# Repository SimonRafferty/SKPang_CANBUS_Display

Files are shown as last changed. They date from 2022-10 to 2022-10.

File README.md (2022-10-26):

# SKPang_CANBUS_Display
Simple example of a CANBUS display based on SKPang / Copperhill board

https://www.skpang.co.uk/products/teensy-4-0-classic-can-can-fd-board-with-480x320-3-5-touch-lcd

or

https://copperhilltech.com/teensy-4-0-classic-can-can-fd-board-with-480x320-3-5-touch-lcd/

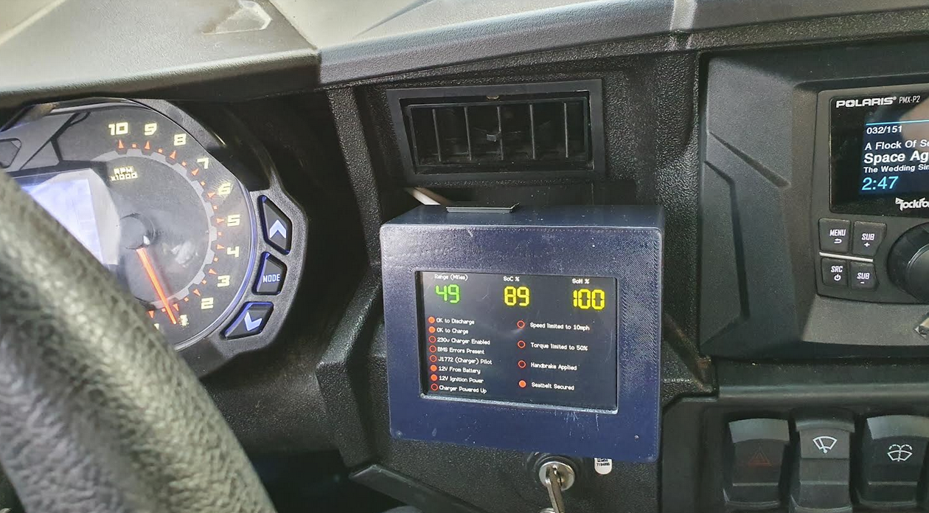
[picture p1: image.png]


I'd bought one of these & found that the example files linked didn't work (for me).  So, here is an example, using the Teensy FLEXCAN library, which does!
I built this for my Polaris General, which I've converted to Electric.

You can see in the code, I'm only receiving two CAN IDs and derriving the display from those.  You'll have to figure out what ID's you want to receive and adapt the code & display accordingly.

Install the TFT_eSPI library from the Arduino IDE.  Then copy the files from the TFT_eSPI folder here to wherever the library was installed, replacing the original files.  These will configure the library to talk to this display.

I've not implemented the touchscreen - but the Adafruit library mentioned in the documentation seemed to work.

This is not intended to be the answer to all your prayers - turnkey solution for your application, just something to get you started in a fruitful direction.
I'm not able to re-write it for you - though I will answer questions when I'm able.

I've also included the files for a 3D printed case.

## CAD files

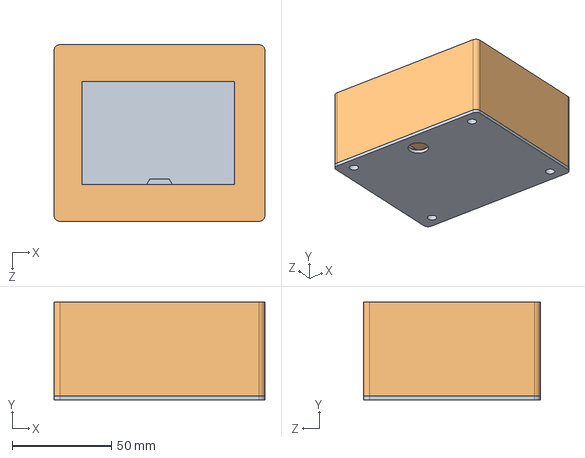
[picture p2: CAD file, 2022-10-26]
3D_Printed_Case/Display Case.SLDASM
106.0 x 49.0 x 88.8 mm
Display Case Back
Display Case Front

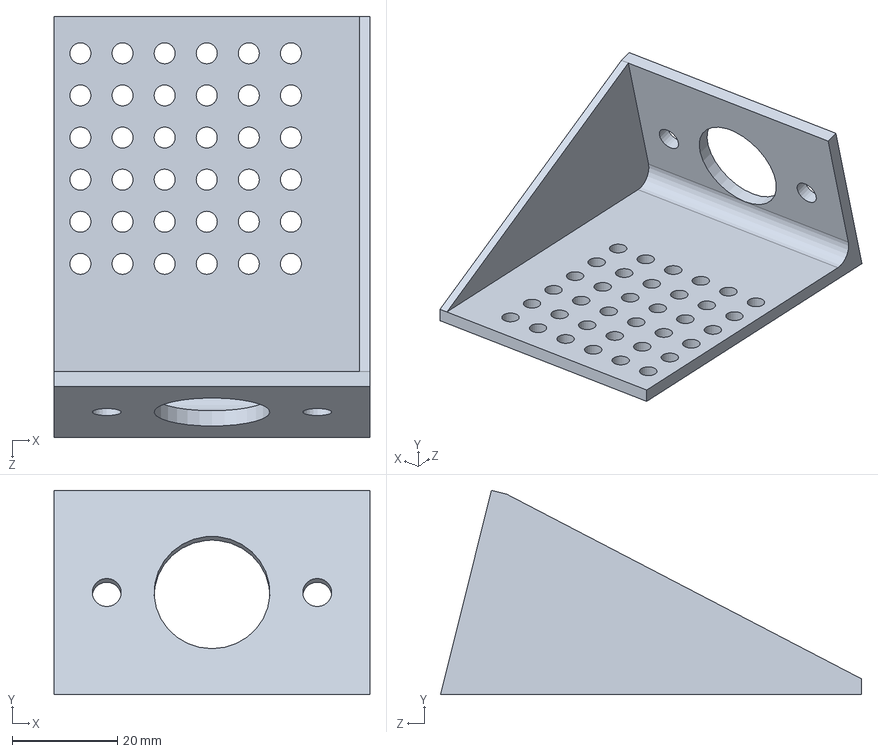
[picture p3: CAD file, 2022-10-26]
3D_Printed_Case/Display Bracket.SLDPRT
60.0 x 38.8 x 80.0 mm

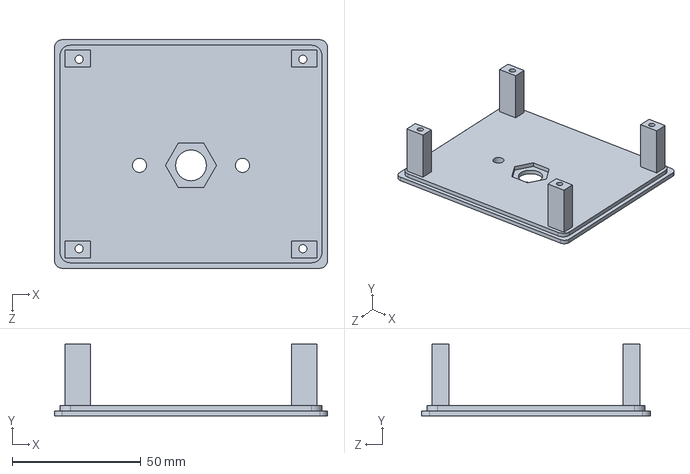
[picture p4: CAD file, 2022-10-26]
3D_Printed_Case/Display Case Back.SLDPRT
106.0 x 27.9 x 88.8 mm

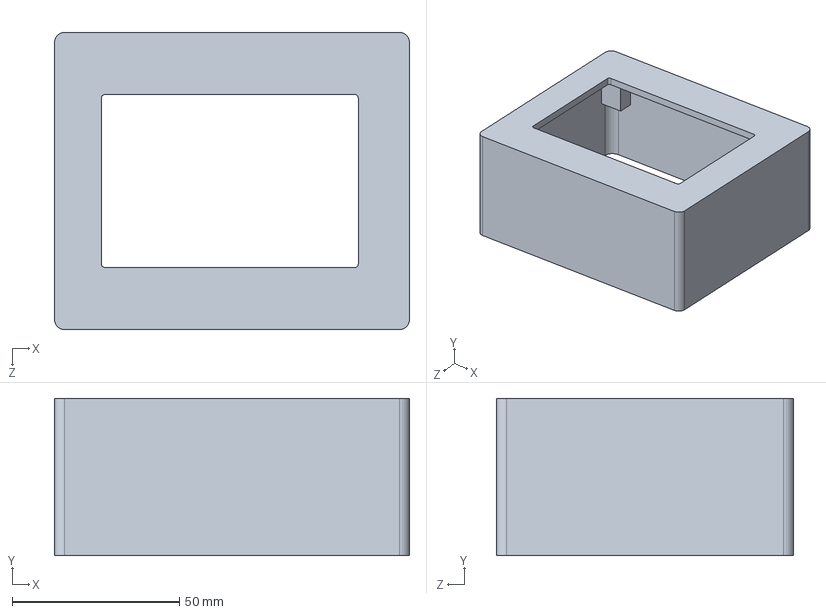
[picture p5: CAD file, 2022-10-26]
3D_Printed_Case/Display Case Front.SLDPRT
106.0 x 47.0 x 88.8 mm

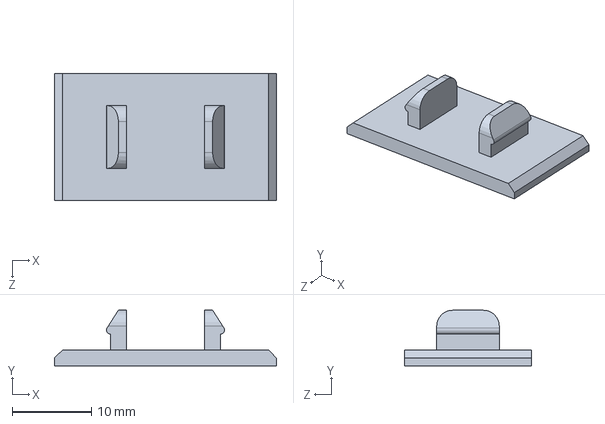
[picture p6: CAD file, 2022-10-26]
3D_Printed_Case/Display USB Cap.SLDPRT
28.0 x 7.00 x 16.0 mm

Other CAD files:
3D_Printed_Case/Display Bracket.STL
3D_Printed_Case/Display Case Back.STL
3D_Printed_Case/Display Case Front.STL
3D_Printed_Case/Display USB Cap.STL

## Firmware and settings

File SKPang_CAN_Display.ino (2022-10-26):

/*
  Board = Teensy 4.0
	Simple diagnostic display, taking data from the 3 port can bridge.
  
  Developed to integrate an Electric Drive Train into a 2021 Polaris General XP 200
  
  CAN_Vehicle Port connects to the Vehicle CAN Harness
  
	Requires the following libraries for Teensy 4.0:

	https://github.com/tonton81/FlexCAN_T4
  TFT_eSPI.h

  You need to configure both User_Setup.h and User_Setup_Select.h
  Uncomment the line in User_Setup_Select.h that includes User_Setup.h, then use it to config the display
  
*/

#include <FlexCAN_T4.h>
#include "canframe.h"
#include <EEPROM.h>
#include <SPI.h>

#include <TFT_eSPI.h> // Hardware-specific library

TFT_eSPI tft = TFT_eSPI();       // Invoke custom library


FlexCAN_T4<CAN3, RX_SIZE_8, TX_SIZE_8> CAN_Vehicle;  //To the vehicle




const double PACK_CAPACITY = 10.9;  //Usable pack size in kWh
const uint32_t CAN_ID_TEENSY         = 0x18FE66FE; //Message from Teensy Bridge (Battery main switch PGN, repurposed)
const uint32_t CAN_ID_ABS_SPEED      = 0x18FEBF0B; //Byte [0] LSB, Byte [1] MSB - Speed from ABS Controller mph x 405
int nSpeed = 0; //Vehicle speed from ABS Controller in kph
int nSOC = 0; //SoC from Teensy 3 Port Bridge
int nSOH = 0; //SoH from Teensy 3 Port Bridge
byte nOrion_Flags = 0; //Orion BMS Flags
byte nPolaris_Flags = 0; //Polaris Stats BMS Flags
int nVoltage; //Pack Voltage
int nCurrent; //Pack Voltage
long lInterval = millis(); //Interval Timer  
int nScreenIndex = 0;  //Which screen are we looking at? 0,1,2
double dRange = 0;
long lMeanRange[200]; //Container for mean range values
int nMRPointer = 0;
int nLastSOC = 0; //SoC from Teensy 3 Port Bridge
int nLastSOH = 0; //SoH from Teensy 3 Port Bridge




//Useful for printing frame data
//Serial.print(" Interface: "); Serial.print(which_interface); Serial.print(" - ");
//Serial.print(" PID: "); Serial.print(frame.get_id(), HEX); Serial.print(" Data: "); 
//print_hex(frame.get_data()->bytes, 8);  








void vehicle_got_frame( const CAN_message_t &orig_frame) {
  CANFrame frame = orig_frame;


  uint32_t lPID = (frame.get_id() & 0x00FFFF00);
  //Serial.print("CAN ID="); Serial.println(frame.get_id(),HEX);
  if(lPID == (CAN_ID_TEENSY & 0x00FFFF00)) {
    nVoltage = (frame.buf[1]*256 + frame.buf[0]);  //Pack Voltage x 10
    //Serial.print(" | Voltage "); Serial.print(nVoltage);
    nCurrent = (frame.buf[3]*256 + frame.buf[2]); //Current x 10
    //Serial.print(" | Current "); Serial.println(nCurrent);
    nOrion_Flags = frame.buf[4]; //Orion Flags
    // [bit 0] Discharge Enable
    // [bit 1] Charge Enable
    // [bit 2] Charger Safety
    // [bit 3] BMS Errors Present
    // [bit 4] Multi-Purpose Input
    // [bit 5] AM Power Status
    // [bit 6] Ready Power Status
    // [bit 7] Charge Power Status
    nPolaris_Flags = frame.buf[5]; //Flags for current state of Teensy
    // [bit 0] Speed Limited
    // [bit 1] Torque Limited
    // [bit 2] Handbrake
    // [bit 3] Seatbelt
    // [bit 4] 
    // [bit 5] 
    // [bit 6] 
    // [bit 7] 
    nSOC = frame.buf[6]; //SoC%
    nSOH = frame.buf[7]; //Pack State of Health%
  }
  if(lPID == (CAN_ID_ABS_SPEED & 0x00FFFF00)) {
    nSpeed = (frame.buf[1]*256 + frame.buf[0]);      
  }
}




void setup()
{
	Serial.begin(115200);
	Serial.println("Polaris CAN Display");
  

	//Teensy FlexCAN_T4 setup
	CAN_Vehicle.begin();
	CAN_Vehicle.setBaudRate(250000);
	CAN_Vehicle.setMaxMB(32);
	CAN_Vehicle.enableFIFO();
	CAN_Vehicle.onReceive(vehicle_got_frame);


	CAN_Vehicle.enableFIFOInterrupt();
	CAN_Vehicle.mailboxStatus();
  
  for(int nCnt=0; nCnt<200; nCnt++) {
    lMeanRange[nCnt] = -1;
  }      


  tft.init();
  tft.setRotation(3);
  tft.fillScreen(TFT_BLACK);
}

void loop(){
//Update the display periodically
long lJoules = 0;
double dWHour = 0;
double dMPS = 0;
double dDistance = 0;
double dWHRemaining = 0;
double dRange = 0;
long lTime;
long lLastJoules = 0;

  if(millis() - lInterval > 500) {
    lTime = millis() - lInterval; //Time since last
    lInterval = millis(); //reset timer

    lJoules = (nVoltage * nCurrent * lTime) / 1000;
    if(lJoules != lLastJoules) {  //Don't calculate if we're in regen
      //Test Data
      //nVoltage = 106; nCurrent = 22; nSpeed = 10; nSOC = 90; nSOH = 100;
      //Calculate power used this interval in WS or Joules
      lLastJoules = lJoules;
      //A Watt hour is 3600J
      dWHour = double(lJoules) / 3600.0;
      if(dWHour == 0) dWHour = 1;
      dMPS = double(nSpeed) / 405.0 * 0.44704; 
      dDistance = dMPS * double(lTime) / 1000.0;
  
      dWHRemaining = PACK_CAPACITY * nSOC * nSOH /10; //Includes battery state of health
      dRange = dWHRemaining / dWHour * dDistance; //in Metres
      dRange = dRange / 1609.0; //Range in Miles
  
      double dMaxRange = 48 * (nSOC + 5) * nSOH /10000;
      if(dMPS < 3) {  //If vehicle isn't moving, range calcs as 0.  
        //Recalculate very simplistically based on 48m per full charge
        dRange = dMaxRange;
      }

      if((dRange>dMaxRange) && (dMaxRange>0)) dRange=dMaxRange;  //Range not likely to be more
      
      if((lMeanRange[1]==-1) && (dMaxRange!=0)) {
        //This is the first run, load the array with current value
        for(int nCnt=0; nCnt<200; nCnt++) {
          lMeanRange[nCnt] = long(dMaxRange);
        }      
      }
      if((dRange!=0) && (dRange!=dMaxRange)) {
        nMRPointer++;
        lMeanRange[nMRPointer] = long(dRange);
      }
/*    
      Serial.print("| Time "); Serial.print(lTime);
      Serial.print(" | lJoules "); Serial.print(lJoules);
      Serial.print(" | dWHour "); Serial.print(dWHour);
      Serial.print(" | Voltage "); Serial.print(nVoltage);
      Serial.print(" | Current "); Serial.print(nCurrent);
      Serial.print(" | dMPS "); Serial.print(dMPS);
      Serial.print(" | dDistance "); Serial.print(dDistance);
      Serial.print(" | dWHRemaining "); Serial.print(dWHRemaining);
      Serial.print(" | nSOC "); Serial.print(nSOC);
      Serial.print(" | dRange "); Serial.println(dRange);
*/
    }
    
    if(nMRPointer>199) nMRPointer=0;

    //Calculate average over the last 200 seconds
    long lAvRange = 0;
    for(int nCnt=0; nCnt<200; nCnt++) {
      lAvRange = lAvRange + lMeanRange[nCnt];
    }
    lAvRange = lAvRange / 200;
    
    DisplayResults(lAvRange); //Average
    //DisplayResults(lMeanRange[nMRPointer]); //Instantaneous
    
  }


}

void DisplayResults(double dDRange) {
//Show data on M5Stack Display
int nHOffset = 105;
int nHeight = (320-nHOffset) / 16;
static double dLastDRange = 0;

  //Range
  tft.setTextColor(TFT_WHITE,TFT_BLACK);
  tft.setCursor(30, 2, 2); //X,Y,Font  Font 7 is a Sever Segment type
  tft.println("Range (Miles)");

  if(dDRange!=-1) {  //Only display if we have some values
    if(dDRange!=dLastDRange) {
      tft.setTextColor(TFT_BLACK,TFT_BLACK);
      tft.setCursor(30, 30, 7); //X,Y,Font  Font 7 is a Sever Segment type
      tft.print(int(dDRange));
      dLastDRange = dDRange;
      tft.setTextColor(TFT_GREEN,TFT_BLACK);
      tft.setCursor(30, 30, 7); //X,Y,Font  Font 7 is a Sever Segment type
      tft.print(int(dDRange));
    }
  }
  //SOC
  tft.setTextColor(TFT_WHITE,TFT_BLACK);
  tft.setCursor(210, 2, 2); //X,Y,Font  Font 7 is a Sever Segment type
  tft.print("SoC %");
  if(nSOC!=nLastSOC) {
    tft.setTextColor(TFT_BLACK,TFT_BLACK);
    tft.setCursor(210, 30, 7); //X,Y,Font  Font 7 is a Sever Segment type
    tft.print(nLastSOC);
    nLastSOC = nSOC;
    tft.setTextColor(TFT_YELLOW,TFT_BLACK);
    tft.setCursor(210, 30, 7); //X,Y,Font  Font 7 is a Sever Segment type
    tft.print(nSOC);
  }
  //SOH
  tft.setTextColor(TFT_WHITE,TFT_BLACK);
  tft.setCursor(380, 2, 2); //X,Y,Font  Font 7 is a Sever Segment type
  tft.println("SoH %");

  if(nSOH!=nLastSOH) {
    tft.setTextColor(TFT_BLACK,TFT_BLACK);
    if(nLastSOH<100) {
      tft.setCursor(380, 30, 7); //X,Y,Font  Font 7 is a Sever Segment type
    } else {
      tft.setCursor(360, 30, 7); //X,Y,Font  Font 7 is a Sever Segment type    
    }
    tft.println(nLastSOH);
    nLastSOH = nSOH;
    tft.setTextColor(TFT_YELLOW,TFT_BLACK);
    if(nSOH<100) {
      tft.setCursor(380, 30, 7); //X,Y,Font  Font 7 is a Sever Segment type
    } else {
      tft.setCursor(360, 30, 7); //X,Y,Font  Font 7 is a Sever Segment type    
    }
    tft.println(nSOH);
  }
  //ORION LEDs
    // [bit 0] Discharge Enable
    // [bit 1] Charge Enable
    // [bit 2] Charger Safety
    // [bit 3] BMS Errors Present
    // [bit 4] Multi-Purpose Input
    // [bit 5] AM Power Status
    // [bit 6] Ready Power Status
    // [bit 7] Charge Power Status
  //Show 8 LEDs equally spaced
  tft.setTextColor(TFT_WHITE,TFT_BLACK);
  tft.setCursor(30, nHOffset+nHeight * 1, 2);tft.println("OK to Discharge");
  tft.setCursor(30, nHOffset+nHeight * 3, 2);tft.println("OK to Charge");
  tft.setCursor(30, nHOffset+nHeight * 5, 2);tft.println("230v Charger Enabled");
  tft.setCursor(30, nHOffset+nHeight * 7, 2);tft.println("BMS Errors Present");
  tft.setCursor(30, nHOffset+nHeight * 9, 2);tft.println("J1772 (Charger) Pilot");
  tft.setCursor(30, nHOffset+nHeight * 11, 2);tft.println("12V From Battery");
  tft.setCursor(30, nHOffset+nHeight * 13, 2);tft.println("12V Ignition Power");
  tft.setCursor(30, nHOffset+nHeight * 15, 2);tft.println("Charger Powered Up");
  
  DisplayLED(15, nHOffset+nHeight * 1,  ((nOrion_Flags & 0B00000001)==0B00000001));
  DisplayLED(15, nHOffset+nHeight * 3,  ((nOrion_Flags & 0B00000010)==0B00000010)); 
  DisplayLED(15, nHOffset+nHeight * 5,  ((nOrion_Flags & 0B00000100)==0B00000100));
  DisplayLED(15, nHOffset+nHeight * 7,  ((nOrion_Flags & 0B00001000)==0B00001000));
  DisplayLED(15, nHOffset+nHeight * 9,  ((nOrion_Flags & 0B00010000)==0B00010000));
  DisplayLED(15, nHOffset+nHeight * 11, ((nOrion_Flags & 0B00100000)==0B00100000));
  DisplayLED(15, nHOffset+nHeight * 13, ((nOrion_Flags & 0B01000000)==0B01000000));
  DisplayLED(15, nHOffset+nHeight * 15, ((nOrion_Flags & 0B10000000)==0B10000000));

  tft.setCursor(275, nHOffset+nHeight * 1, 2);tft.println("Speed limited to 10mph");
  tft.setCursor(275, nHOffset+nHeight * 5, 2);tft.println("Torque limited to 50%");
  tft.setCursor(275, nHOffset+nHeight * 9, 2);tft.println("Handbrake Applied");
  tft.setCursor(275, nHOffset+nHeight * 13, 2);tft.println("Seatbelt Secured");

  //Show 4 LEDs equally spaced
  DisplayLED(250, nHOffset+nHeight * 1, ((nPolaris_Flags & 0B10000000)==0B10000000));
  DisplayLED(250, nHOffset+nHeight * 5, ((nPolaris_Flags & 0B01000000)==0B01000000));
  DisplayLED(250, nHOffset+nHeight * 9, ((nPolaris_Flags & 0B00100000)==0B00100000));
  DisplayLED(250, nHOffset+nHeight * 13, ((nPolaris_Flags & 0B00010000)==0B00010000));
   
  
}


void DisplayLED(int x, int y,bool bON) {
//Display an LED centred on X,Y
int nYOffset = y + 8;
#define TFT_GREY 0x7BEF

  if(bON) {
    tft.fillCircle(x, nYOffset, 8, TFT_RED);
    tft.drawCircle(x, nYOffset, 8, TFT_GREY);
  } else {
    tft.fillCircle(x, nYOffset, 8, TFT_BLACK);
    tft.drawCircle(x, nYOffset, 8, TFT_RED);
  }  
  
  
}

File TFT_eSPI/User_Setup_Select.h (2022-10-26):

// This header file contains a list of user setup files and defines which one the
// compiler uses when the IDE performs a Verify/Compile or Upload.
//
// Users can create configurations for different Espressif boards and TFT displays.
// This makes selecting between hardware setups easy by "uncommenting" one line.

// The advantage of this hardware configuration method is that the examples provided
// with the library should work with different setups immediately without any other
// changes being needed. It also improves the portability of users sketches to other
// hardware configurations and compatible libraries.
//
// Create a shortcut to this file on your desktop to permit quick access for editing.
// Re-compile and upload after making and saving any changes to this file.

// Customised User_Setup files are stored in the "User_Setups" folder.

#ifndef USER_SETUP_LOADED //  Lets PlatformIO users define settings in
//  platformio.ini, see notes in "Tools" folder.

// Only ONE line below should be uncommented.  Add extra lines and files as needed.

 #include <User_Setup.h>           // Default setup is root library folder

//#include <User_Setups/Setup1_ILI9341.h>  // Setup file configured for my ILI9341
//#include <User_Setups/Setup2_ST7735.h>   // Setup file configured for my ST7735
//#include <User_Setups/Setup3_ILI9163.h>  // Setup file configured for my ILI9163
//#include <User_Setups/Setup4_S6D02A1.h>  // Setup file configured for my S6D02A1
//#include <User_Setups/Setup5_RPi_ILI9486.h>        // Setup file configured for my stock RPi TFT
//#include <User_Setups/Setup6_RPi_Wr_ILI9486.h>     // Setup file configured for my modified RPi TFT
//#include <User_Setups/Setup7_ST7735_128x128.h>     // Setup file configured for my ST7735 128x128 display
//#include <User_Setups/Setup8_ILI9163_128x128.h>    // Setup file configured for my ILI9163 128x128 display
//#include <User_Setups/Setup9_ST7735_Overlap.h>     // Setup file configured for my ST7735
//#include <User_Setups/Setup10_RPi_touch_ILI9486.h> // Setup file configured for ESP8266 and RPi TFT with touch

//#include <User_Setups/Setup11_RPi_touch_ILI9486.h> // Setup file configured for ESP32 and RPi TFT with touch
//#include <User_Setups/Setup12_M5Stack.h>           // Setup file for the ESP32 based M5Stack
//#include <User_Setups/Setup13_ILI9481_Parallel.h>  // Setup file for the ESP32 with parallel bus TFT
//#include <User_Setups/Setup14_ILI9341_Parallel.h>  // Setup file for the ESP32 with parallel bus TFT
//#include <User_Setups/Setup15_HX8357D.h>           // Setup file configured for HX8357D (untested)
//#include <User_Setups/Setup16_ILI9488_Parallel.h>  // Setup file for the ESP32 with parallel bus TFT
//#include <User_Setups/Setup17_ePaper.h>            // Setup file for any Waveshare ePaper display
//#include <User_Setups/Setup18_ST7789.h>            // Setup file configured for ST7789

//#include <User_Setups/Setup19_RM68140_Parallel.h>  // Setup file configured for RM68140 with parallel bus

//#include <User_Setups/Setup20_ILI9488.h>           // Setup file for ESP8266 and ILI9488 SPI bus TFT
//#include <User_Setups/Setup21_ILI9488.h>           // Setup file for ESP32 and ILI9488 SPI bus TFT

//#include <User_Setups/Setup22_TTGO_T4.h>           // Setup file for ESP32 and TTGO T4 version 1.2
//#include <User_Setups/Setup22_TTGO_T4_v1.3.h>      // Setup file for ESP32 and TTGO T4 version 1.3
//#include <User_Setups/Setup23_TTGO_TM.h>           // Setup file for ESP32 and TTGO TM ST7789 SPI bus TFT
//#include <User_Setups/Setup24_ST7789.h>            // Setup file configured for ST7789 240 x 240
//#include <User_Setups/Setup25_TTGO_T_Display.h>    // Setup file for ESP32 and TTGO T-Display ST7789V SPI bus TFT
//#include <User_Setups/Setup26_TTGO_T_Wristband.h>  // Setup file for ESP32 and TTGO T-Wristband ST7735 SPI bus TFT

//#include <User_Setups/Setup27_RPi_ST7796_ESP32.h>    // ESP32   RPi MHS-4.0 inch Display-B
//#include <User_Setups/Setup28_RPi_ST7796_ESP8266.h>  // ESP8266 RPi MHS-4.0 inch Display-B

//#include <User_Setups/Setup29_ILI9341_STM32.h>          // Setup for Nucleo board
//#include <User_Setups/Setup30_ILI9341_Parallel_STM32.h> // Setup for Nucleo board and parallel display
//#include <User_Setups/Setup31_ST7796_Parallel_STM32.h>  // Setup for Nucleo board and parallel display
//#include <User_Setups/Setup32_ILI9341_STM32F103.h>      // Setup for "Blue/Black Pill"

//#include <User_Setups/Setup33_RPi_ILI9486_STM32.h>      // Setup for Nucleo board

//#include <User_Setups/Setup34_ILI9481_Parallel_STM32.h> // Setup for Nucleo board and parallel display
//#include <User_Setups/Setup35_ILI9341_STM32_Port_Bus.h> // Setup for STM32 port A parallel display

//#include <User_Setups/Setup36_RPi_touch_ILI9341.h>      // Setup file configured for ESP32 and RPi TFT with touch

//#include <User_Setups/Setup43_ST7735.h>            // Setup file configured for my ST7735S 80x160
//#include <User_Setups/Setup44_TTGO_CameraPlus.h>   // Setup file for ESP32 and TTGO T-CameraPlus ST7789 SPI bus TFT    240x240
//#include <User_Setups/Setup45_TTGO_T_Watch.h>      // Setup file for ESP32 and TTGO T-Watch ST7789 SPI bus TFT  240x240

//#include <User_Setups/Setup135_ST7789.h>           // Setup file for ESP8266 and ST7789 135 x 240 TFT

//#include <User_Setups/SetupX_Template.h>


#endif // USER_SETUP_LOADED



/////////////////////////////////////////////////////////////////////////////////////
//                                                                                 //
//     DON'T TINKER WITH ANY OF THE FOLLOWING LINES, THESE ADD THE TFT DRIVERS     //
//       AND ESP8266 PIN DEFINITONS, THEY ARE HERE FOR BODMER'S CONVENIENCE!       //
//                                                                                 //
/////////////////////////////////////////////////////////////////////////////////////


// Identical looking TFT displays may have a different colour ordering in the 16 bit colour
#define TFT_BGR 0   // Colour order Blue-Green-Red
#define TFT_RGB 1   // Colour order Red-Green-Blue

// Legacy setup support, RPI_DISPLAY_TYPE replaces RPI_DRIVER
#if defined (RPI_DRIVER)
#if !defined (RPI_DISPLAY_TYPE)
#define RPI_DISPLAY_TYPE
#endif
#endif

// Legacy setup support, RPI_ILI9486_DRIVER form is deprecated
// Instead define RPI_DISPLAY_TYPE and also define driver (e.g. ILI9486_DRIVER)
#if defined (RPI_ILI9486_DRIVER)
#if !defined (ILI9486_DRIVER)
#define ILI9486_DRIVER
#endif
#if !defined (RPI_DISPLAY_TYPE)
#define RPI_DISPLAY_TYPE
#endif
#endif
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
